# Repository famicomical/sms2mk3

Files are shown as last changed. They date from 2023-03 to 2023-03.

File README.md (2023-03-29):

# sms2mk3

Play your US Sega Master System games on a Japanese console. 
The compact design of this board reduces its cost and allows for more flexibility in mounting compared to other options on the market.

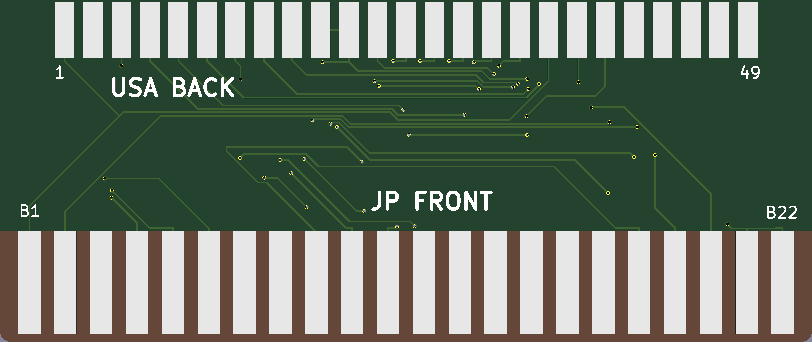
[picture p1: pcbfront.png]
front


The sms2mk3 has the correct vertical size to fit inside a Sega Mark III or Japanese SMS cartridge. It was initially designed to re-use a Japanese Mark III cartridge as housing for a first-generation (legacy) Krikzz Master Everdrive. The design has been tested and confirmed to work for this use case.

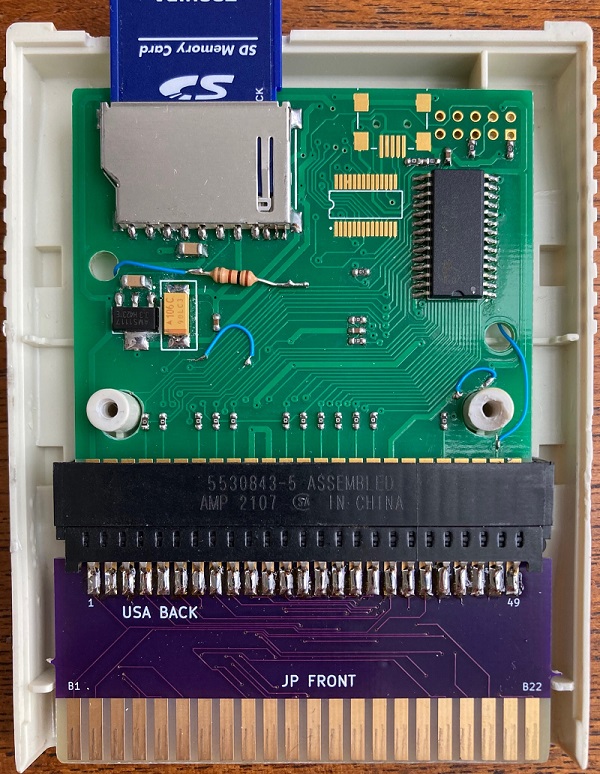
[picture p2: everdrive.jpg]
mounted in housing


Due to the recessed backs of these cartrdiges, case cutting may be necessary to fit the cartrdige slot. Alternatively, you can use the quick-solder board to permanently affix your US cartridge to the converter board, and you will be able to fit it all inside a Japanese Sega cartridge without external case cuts.

## Future goals

This project would most effectively be used with a newly manufactured plastic shell which has had its mounting extrusions correctly aligned with the screw holes on a US Master System game PCB. This would allow for a direct fit of the game and converter PCB assembly inside the housing. i haven't attempted 3D modeling the shell yet.

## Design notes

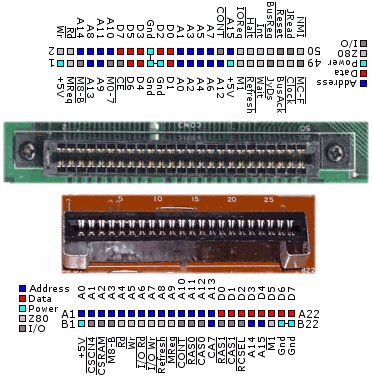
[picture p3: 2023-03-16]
pinout_compare.bmp

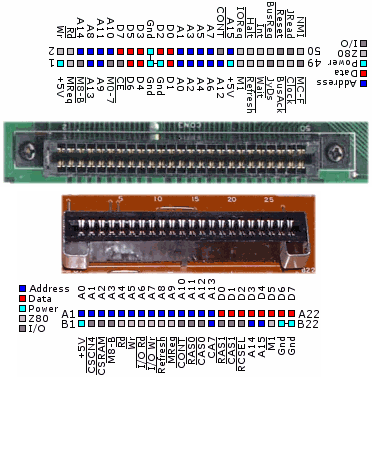
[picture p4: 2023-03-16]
5xyg78ft.bmp

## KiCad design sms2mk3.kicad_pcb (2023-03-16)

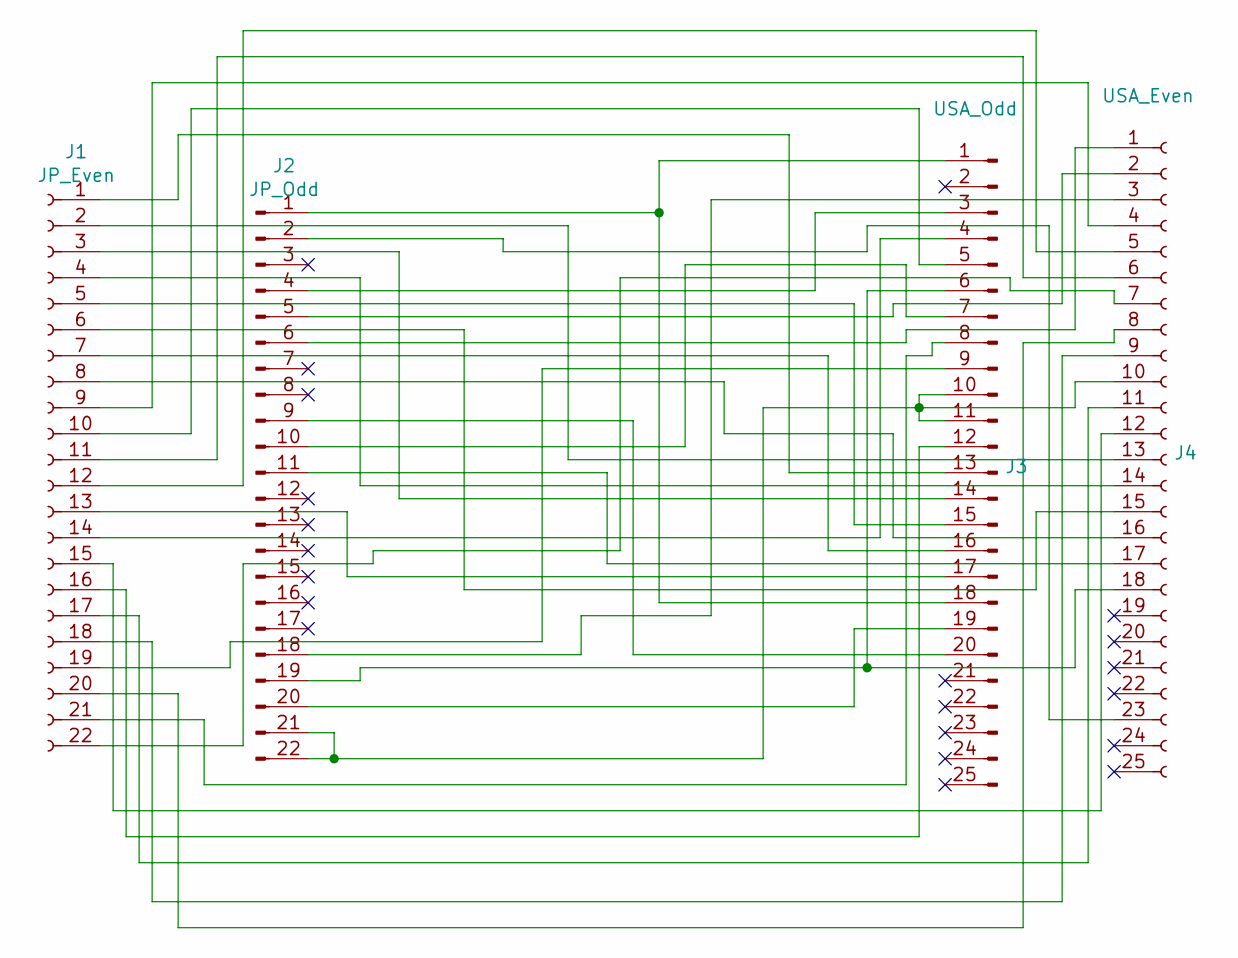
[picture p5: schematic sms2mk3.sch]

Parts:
J1: JP_Even; JP_SMS
J2: JP_Odd; JP_SMS
J3: USA_Odd; US_SMS
J4: USA_Even; US_SMS

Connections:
unnamed: J1.1, J3.13
unnamed: J1.2, J4.13
unnamed: J1.3, J3.14
unnamed: J1.4, J4.14
unnamed: J1.5, J3.15
unnamed: J1.6, J4.15
unnamed: J1.7, J3.16
unnamed: J1.8, J4.16
unnamed: J1.9, J4.4
unnamed: J1.10, J3.5
unnamed: J1.11, J4.6
unnamed: J1.12, J4.5
unnamed: J1.13, J3.17
unnamed: J1.14, J3.4
unnamed: J1.15, J4.12
unnamed: J1.16, J3.12
unnamed: J1.17, J4.11
unnamed: J1.18, J4.9
unnamed: J1.19, J3.9
unnamed: J1.20, J4.8
unnamed: J1.21, J3.8
unnamed: J1.22, J4.7
unnamed: J2.1, J3.1, J3.18
unnamed: J2.2, J4.23
unnamed: J2.4, J3.3
unnamed: J2.5, J4.2
unnamed: J2.6, J4.1
unnamed: J2.9, J3.20
unnamed: J2.10, J3.7
unnamed: J2.11, J4.17
unnamed: J2.18, J4.3
unnamed: J2.19, J3.6, J4.18
unnamed: J2.20, J3.19
unnamed: J2.21, J2.22, J3.10, J3.11, J4.10

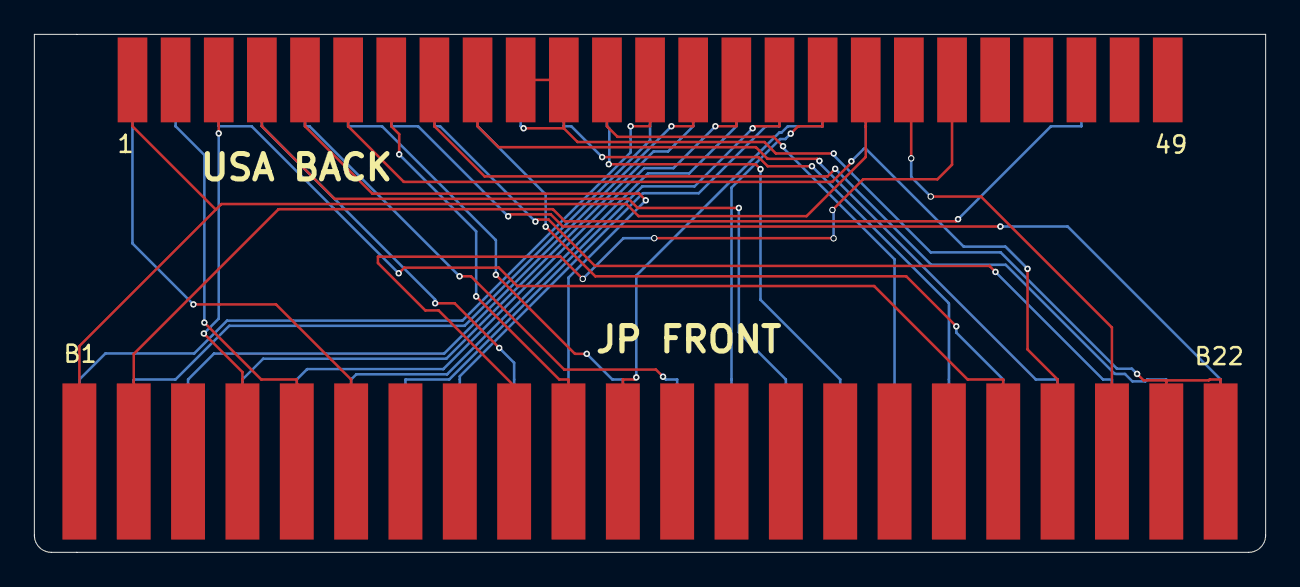
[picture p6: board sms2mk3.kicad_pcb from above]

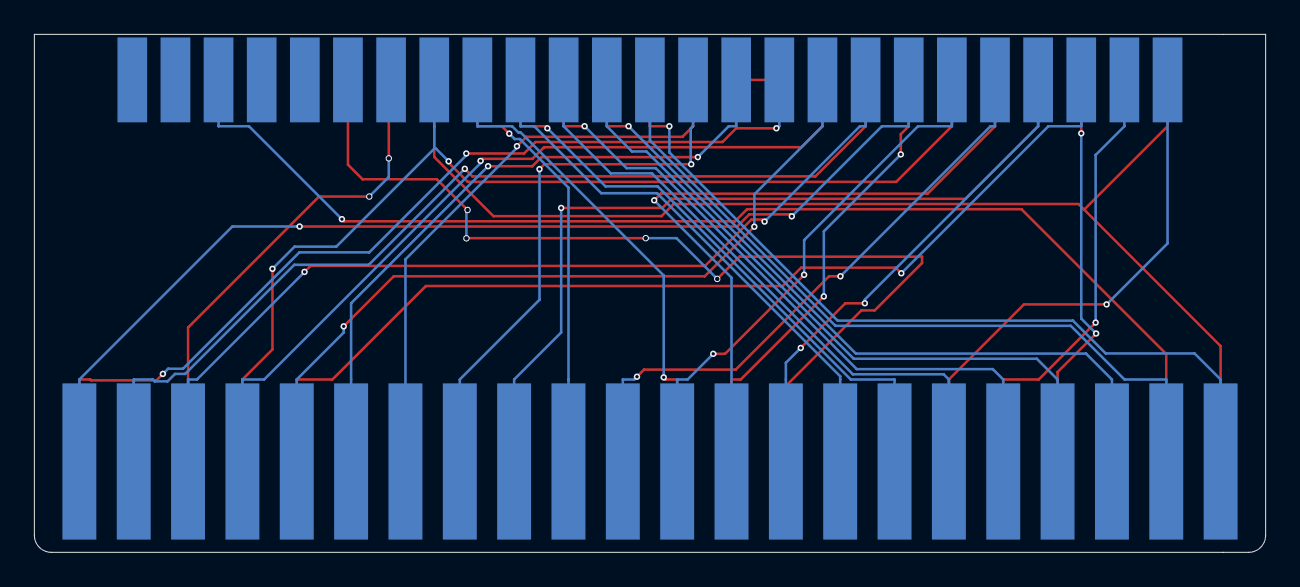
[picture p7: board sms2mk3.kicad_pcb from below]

Board: 2 copper layers, 72.5 x 30.5 mm, 4 parts (2 on the bottom side), 34 nets.

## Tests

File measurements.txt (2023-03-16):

bottom edge of ED to center drill: 14.5mm
side edge to center drill: 6.5mm
drill hole diameter: 7mm

dist from bottom edge of everdrive to bottom edge of converter 37.5mm
dist from bottom edge of ED to top edge of converter: 14.5+.5-8 = 7mm
->converter is 30.5mm long

use AMP 5530843-5 for connector
